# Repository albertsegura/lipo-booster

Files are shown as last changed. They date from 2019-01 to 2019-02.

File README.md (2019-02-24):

# lipo-booster

Power board charges LIPO battery at 1000mA from USB, supplies 5V @ 2A with load sharing.

Based on Adafruit [PowerBooster 1000c](https://www.adafruit.com/product/2465) but featuring hand-solderable ICs!

Features:
* LIPO Charger Controller Microchip [MCP73833](http://ww1.microchip.com/downloads/en/DeviceDoc/22005b.pdf)
* Synchronous Boost Converter Texas Instrument [TPS61032](http://www.ti.com/lit/ds/symlink/tps61032.pdf)
* Load Sharing Circuit based on Microchip [AN1149](http://ww1.microchip.com/downloads/en/appnotes/01149c.pdf)

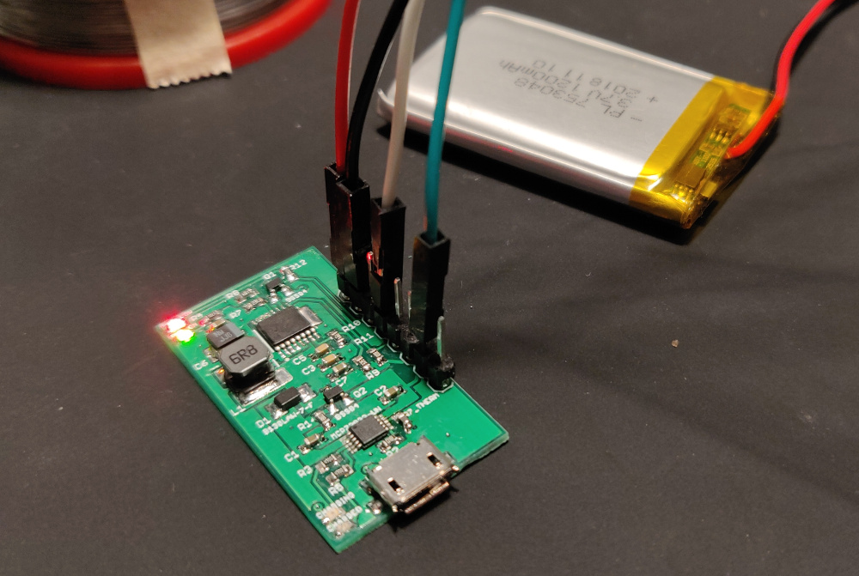
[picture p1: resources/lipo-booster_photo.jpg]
lipo-booster_front


<div>
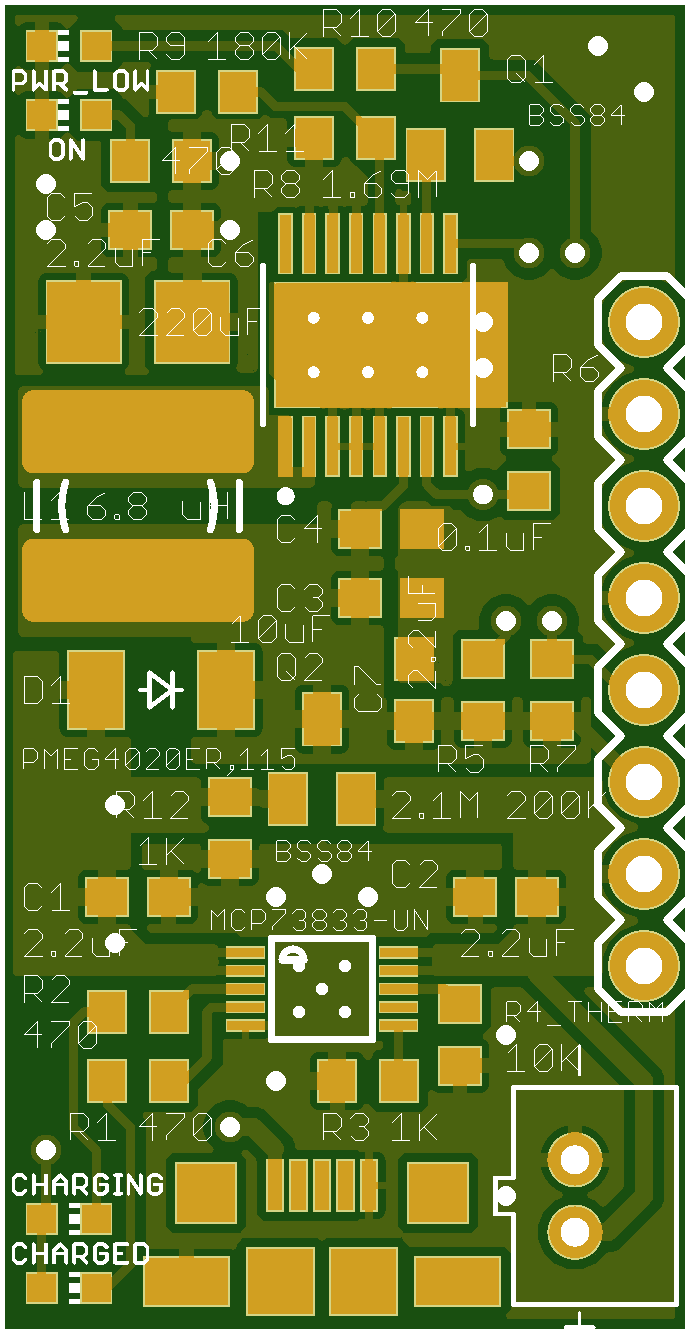
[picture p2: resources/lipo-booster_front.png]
lipo-booster_front

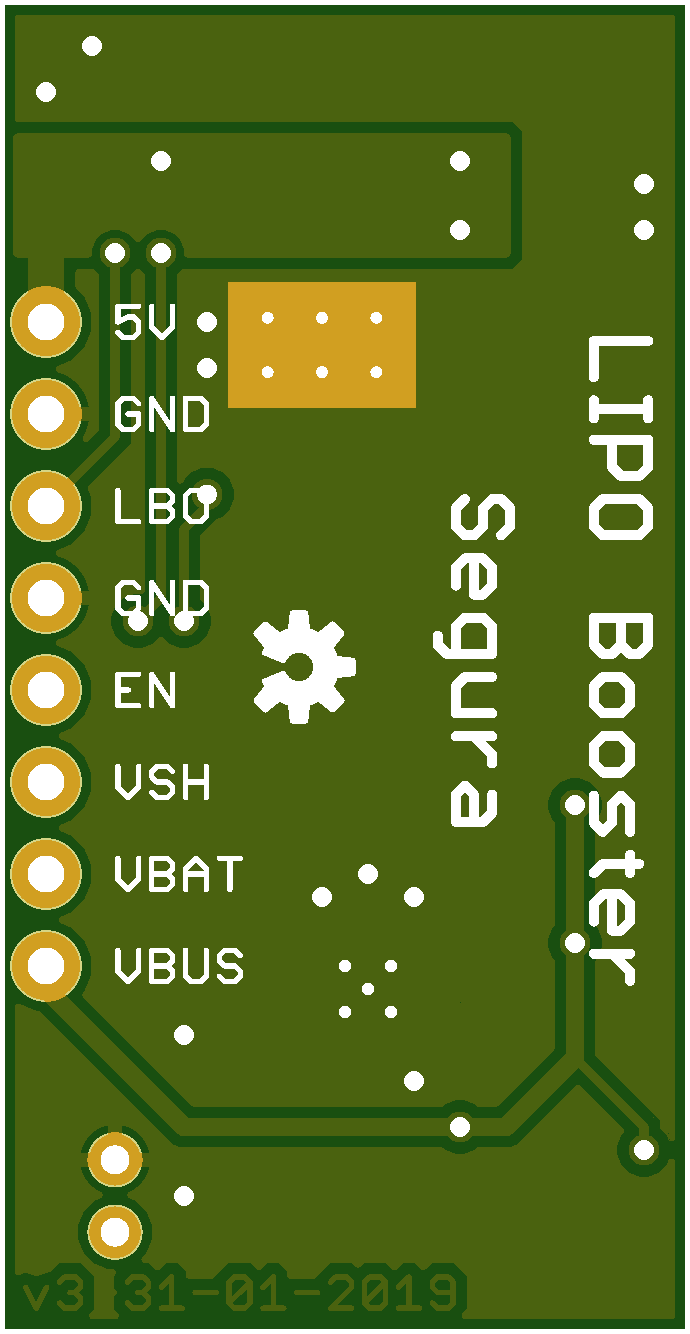
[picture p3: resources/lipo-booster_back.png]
lipo-booster_back

</div>

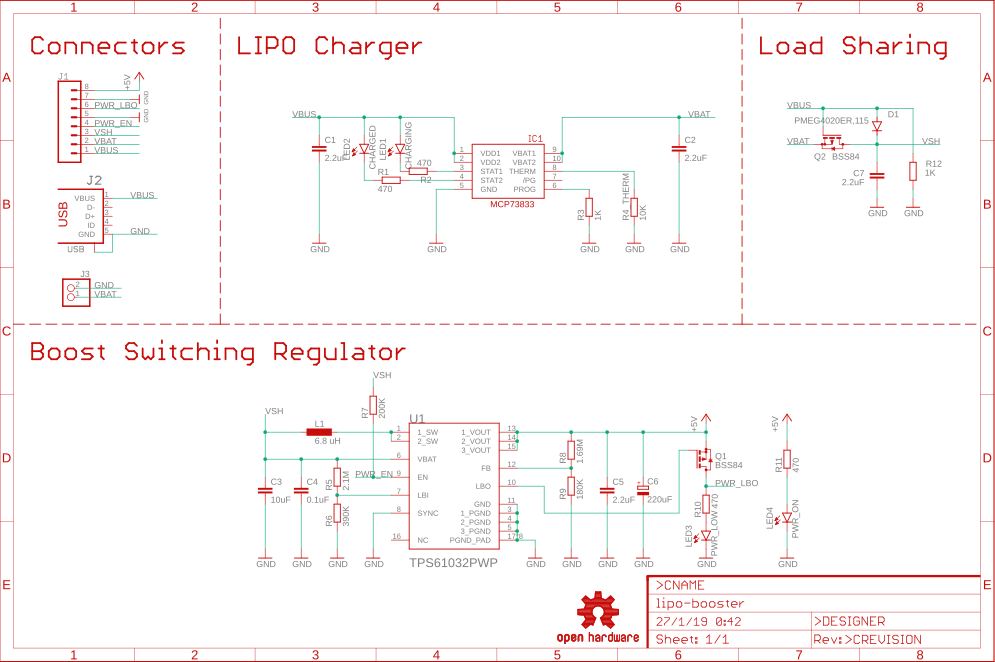
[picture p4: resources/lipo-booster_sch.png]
lipo-booster_sch


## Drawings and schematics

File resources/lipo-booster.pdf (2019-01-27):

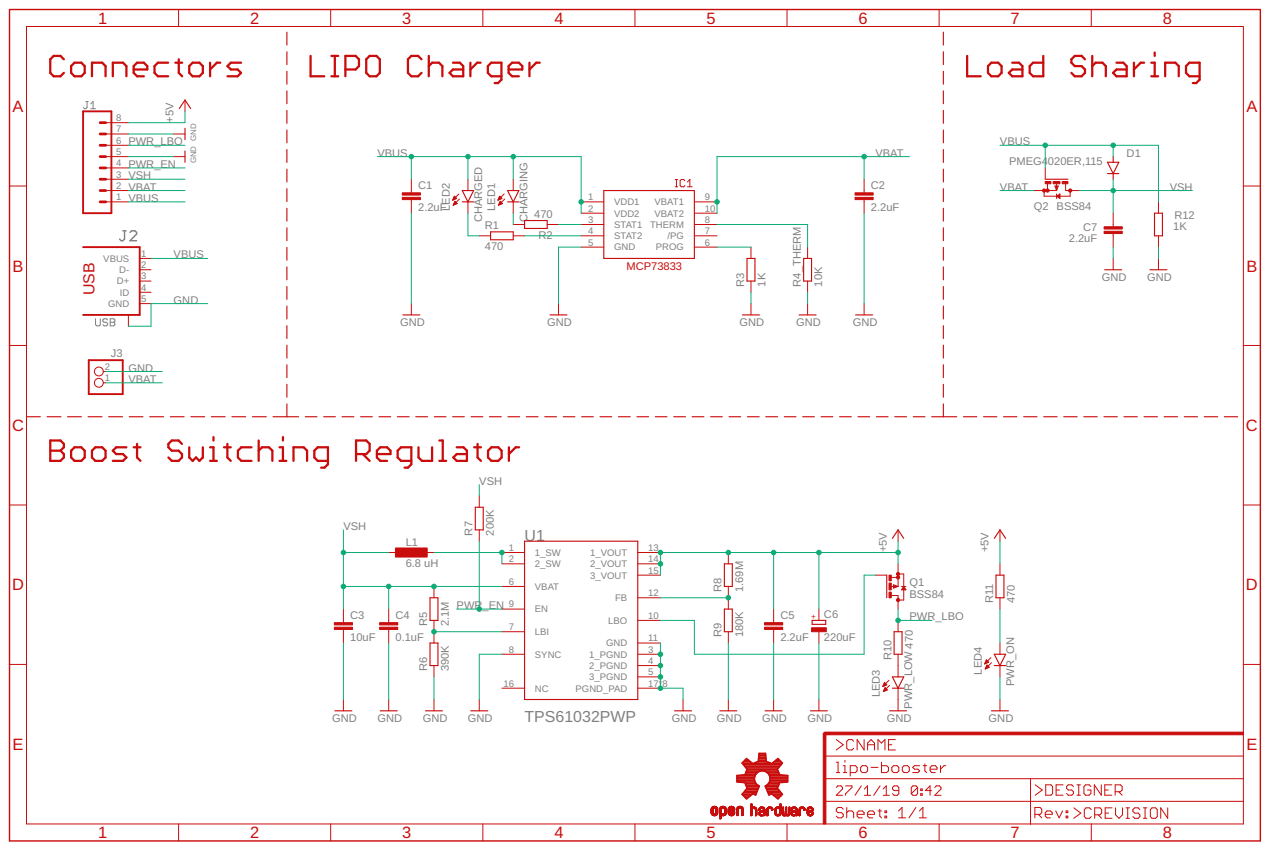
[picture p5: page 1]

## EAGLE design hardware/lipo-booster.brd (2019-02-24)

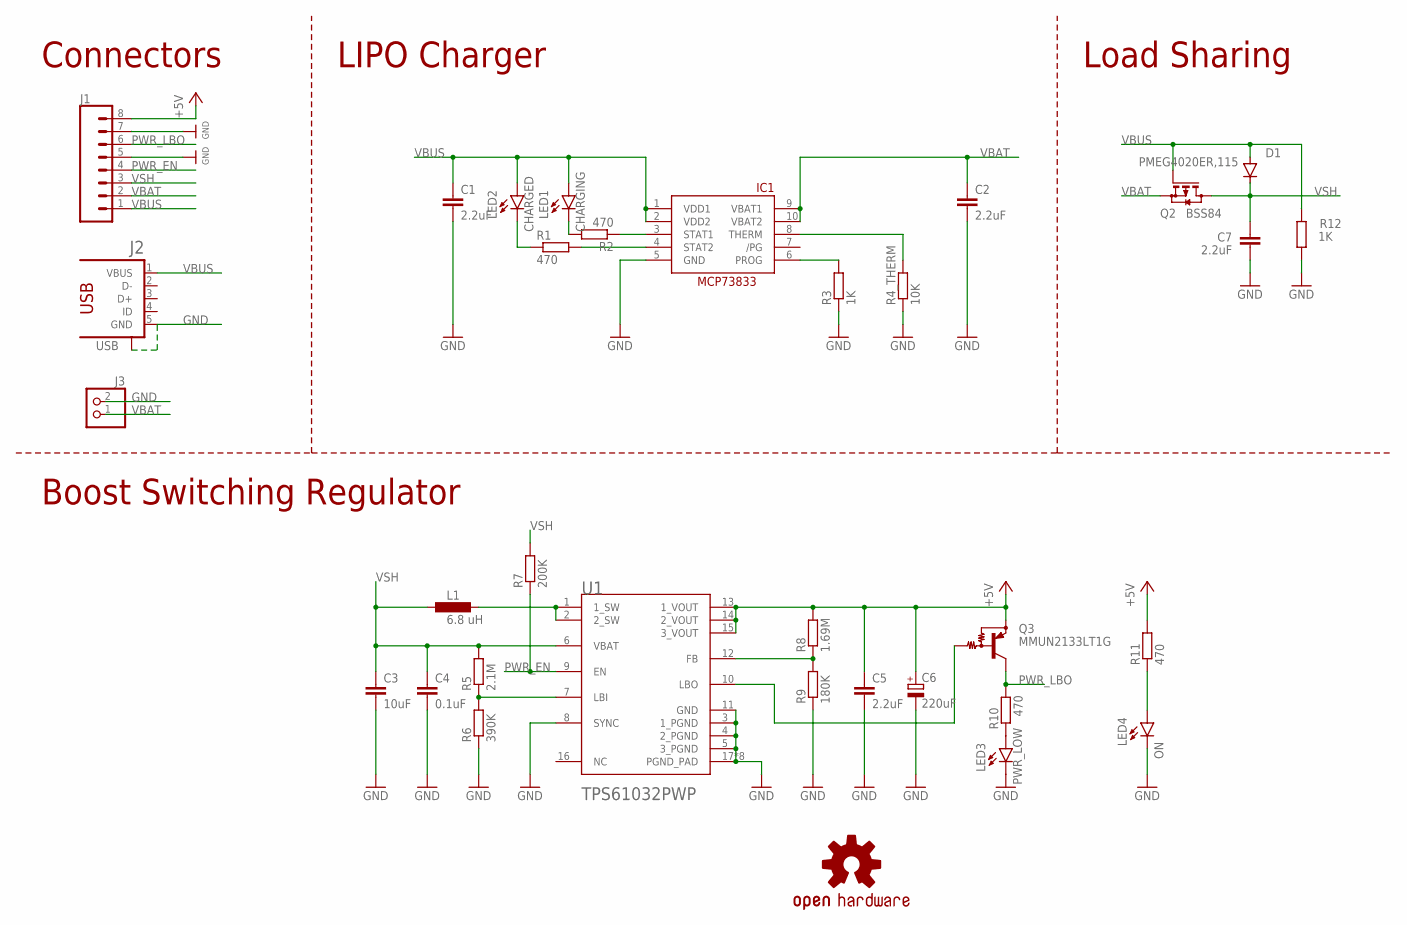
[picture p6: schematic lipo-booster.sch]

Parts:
C1, C2, C5, C7: 2.2uF; C0603
C3: 10uF; C0603
C4: 0.1uF; C0603
C6: 220uF; CT3528
D1: PMEG4020ER,115; SOD-123_MINI-SMA
IC1: MCP73833-UN; MSOP10
J1: CONN_08"; 1X08
J2: USB; 1981584-1
J3: JST_2PIN-THM; JST-PH-2-THM
L1: 6.8 uH; POWER-CHOKE_WE-TPC
LED1: CHARGING; CHIP-LED0603
LED2: CHARGED; CHIP-LED0603
LED3: PWR_LOW; CHIP-LED0603
LED4: ON; CHIP-LED0603
LOGO1: OSHW-LOGOS; OSHW-LOGO-S
Q2: BSS84; SOT23
Q3: MMUN2133LT1G; SC59-BEC
R1, R2, R10, R11: 470; R0603
R3, R12: 1K; R0603
R4_THERM: 10K; R0603
R5: 2.1M; R0603
R6: 390K; R0603
R7: 200K; R0603
R8: 1.69M; R0603
R9: 180K; R0603
U1: TEXAS_INSTRUMENTS_TPS61032PWPTEXAS_INSTRUMENTS_TP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; TEXAS_INSTRUMENTS_TPS61032PWP_0

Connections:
+5V: C5.1, C6.- (+), J1.8, Q3.E, R8.2, R11.2, U1.13 (1_VOUT), U1.14 (2_VOUT), U1.15 (3_VOUT)
GND: C1.2, C2.2, C3.2, C4.2, C5.2, C6.+ (-), C7.2, IC1.5 (GND), J1.5, J1.7, J2.5 (GND), J2.S1, J3.2 (1), LED3.C, LED4.C, R3.1, R4_THERM.1, R6.1, R9.1, R12.1, U1.3 (1_PGND), U1.4 (2_PGND), U1.5 (3_PGND), U1.8 (SYNC), U1.11 (GND), U1.17 (PGND_PAD), U1.PAD_1 (PGND_PAD), U1.PAD_2 (PGND_PAD), U1.PAD_3 (PGND_PAD), U1.PAD_4 (PGND_PAD), U1.PAD_5 (PGND_PAD), U1.PAD_6 (PGND_PAD), U1.SMD_33 (PGND_PAD)
unnamed: L1.1, U1.1 (1_SW), U1.2 (2_SW)
unnamed: LED4.A, R11.1
unnamed: LED3.A, R10.1
unnamed: IC1.8 (THERM), R4_THERM.2
unnamed: IC1.3 (STAT1), R2.1
unnamed: IC1.4 (STAT2), R1.2
unnamed: LED1.C, R2.2
unnamed: IC1.6 (PROG), R3.2
unnamed: LED2.C, R1.1
unnamed: R5.1, R6.2, U1.7 (LBI)
unnamed: Q3.B, U1.10 (LBO)
unnamed: R8.1, R9.2, U1.12 (FB)
PWR_EN: J1.4, R7.1, U1.9 (EN)
PWR_LBO: J1.6, Q3.C, R10.2
VBAT: C2.1, IC1.9 (VBAT1), IC1.10 (VBAT2), J1.2, J3.1 (2), Q2.2 (S)
VBUS: C1.1, D1.A, IC1.1 (VDD1), IC1.2 (VDD2), J1.1, J2.1 (VBUS), LED1.A, LED2.A, Q2.1 (G), R12.2
VSH: C3.1, C4.1, C7.1, D1.C, J1.3, L1.2, Q2.3 (D), R5.2, R7.2, U1.6 (VBAT)

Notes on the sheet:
LIPO Charger
Load Sharing
Boost Switching Regulator
Connectors

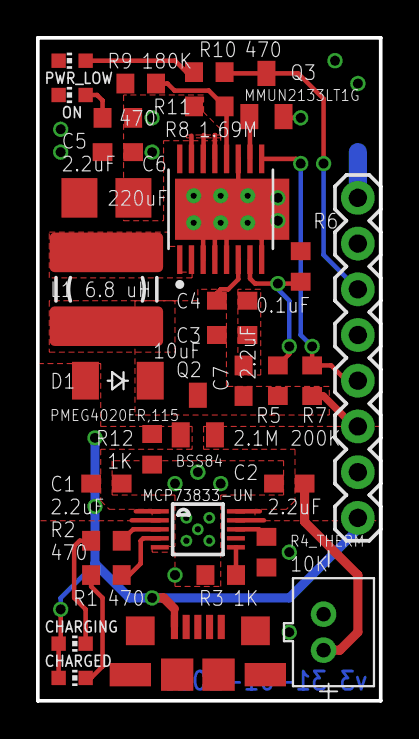
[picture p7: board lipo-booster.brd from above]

Board: 2 copper layers, 19.1 x 36.8 mm, 33 parts (1 on the bottom side), 19 nets.

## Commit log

2019-01-27 Added aditional resources ORganized directories
    [lipo-booster.brd, lipo-booster.sch]
2019-01-27 Added schematics svg
2019-02-05 Updated design with pcb layout suggestions from reddit thread
    [lipo-booster.brd, lipo-booster.sch]
2019-02-24 Small change to schematic to change transistor and update of photo
    [lipo-booster.brd, lipo-booster.sch]

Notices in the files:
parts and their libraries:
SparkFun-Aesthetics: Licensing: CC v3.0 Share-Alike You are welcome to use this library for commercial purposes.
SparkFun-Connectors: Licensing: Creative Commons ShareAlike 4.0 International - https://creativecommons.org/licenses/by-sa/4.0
